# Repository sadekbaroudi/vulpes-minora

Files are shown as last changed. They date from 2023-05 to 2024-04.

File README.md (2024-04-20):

# vulpes minora

This is a 36 key split pcb, specifically designed with the intent to demonstrate a VIK certified keyboard. Read all about that in the [vik github repository](https://github.com/sadekbaroudi/vik)

## Features

vulpes minora supports the following features:
* 36 keys
* Reversible PCB
* MX / Choc / KS-27 and KS-33 switch support, hotswap only
* Underglow
* EC11 rotary encoders (byo-mcu and RP2040-Zero version only)
* Audio buzzer (byo-mcu only)
* VIK support (byo-mcu and RP2040-Zero version only)
* Wireless + VIK support (using nice!nano controller, byo-mcu version only)

Note: while the xiao-xivik version doesn't support VIK, the intent of this PCB is to allow you to build a vulpes majora using a [xivik controller](https://fingerpunch.xyz/product/xivik), which **does** provide you VIK support

## VIK keyboard certification card

| Category | Classification | Response |
| ---  | --- | --- |
| FPC connector | Required | :heavy_check_mark: |
| Breakout pins | Recommended | :x: |
| Supplies: SPI | Strongly recommended | :heavy_check_mark: |
| Supplies: I2C | Strongly recommended | :heavy_check_mark: |
| I2C on main PCB | Discouraged | :x: |
| I2C pull ups | Informative | N/A |
| Supplies: RGB | Strongly recommended | :heavy_check_mark: |
| Supplies: Extra GPIO | Strongly recommended | :heavy_check_mark: |

## Build pics

This is a build using the [byo-mcu pcb](https://github.com/sadekbaroudi/vulpes-minora/tree/master/pcb/byo-mcu) keyboard pcb and the [per56-cirque-leds](https://github.com/sadekbaroudi/vik/tree/master/pcb/per56-cirque-leds) module.

vulpes-minora-cirque-scroll-wheel-full-in-dark

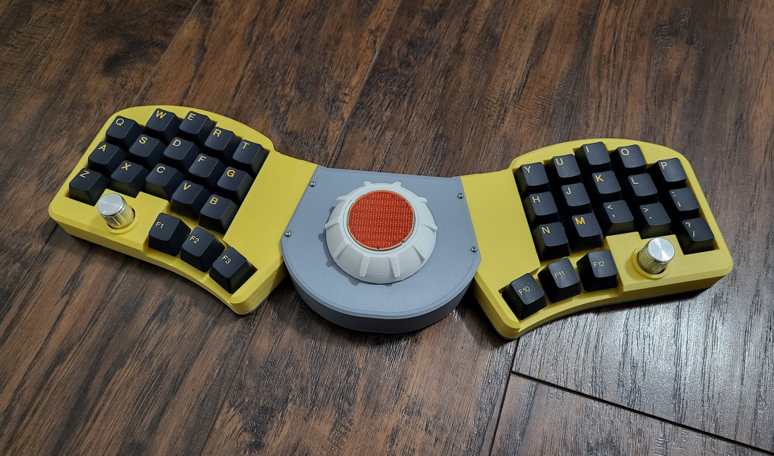
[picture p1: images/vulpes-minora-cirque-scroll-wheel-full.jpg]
vulpes-minora-cirque-scroll-wheel-full


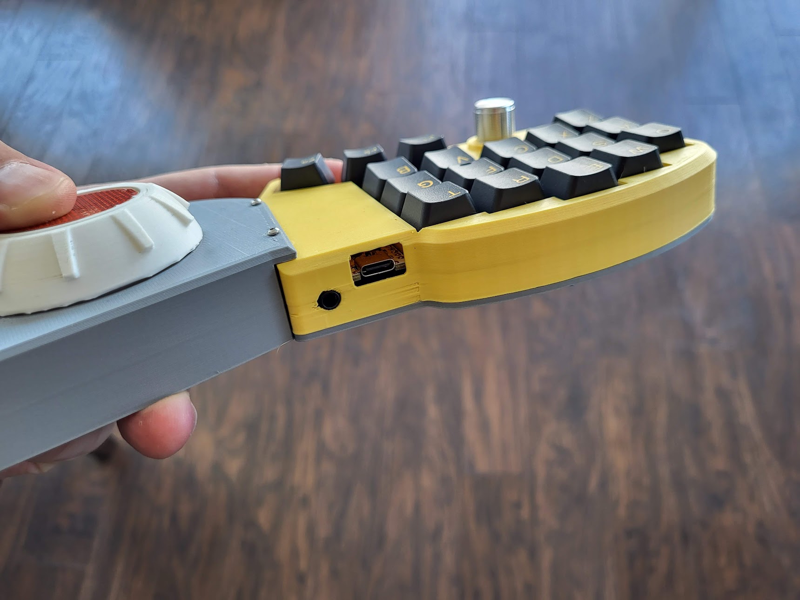
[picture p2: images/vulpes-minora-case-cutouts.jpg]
vulpes-minora-case-cutouts


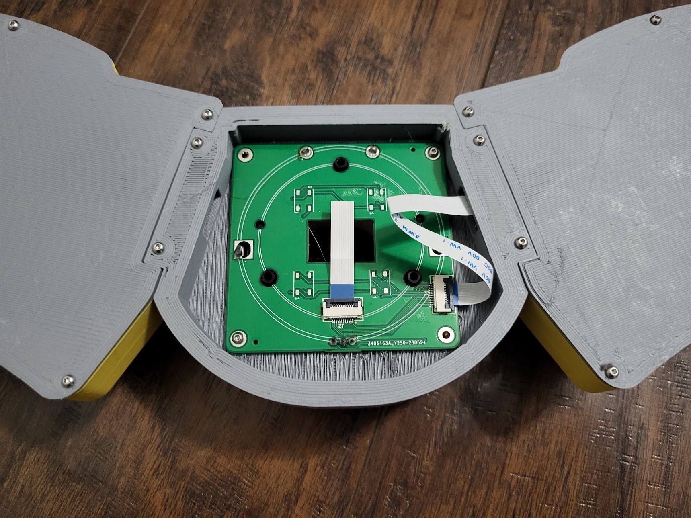
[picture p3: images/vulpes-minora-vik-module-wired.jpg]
vulpes-minora-vik-module-wired


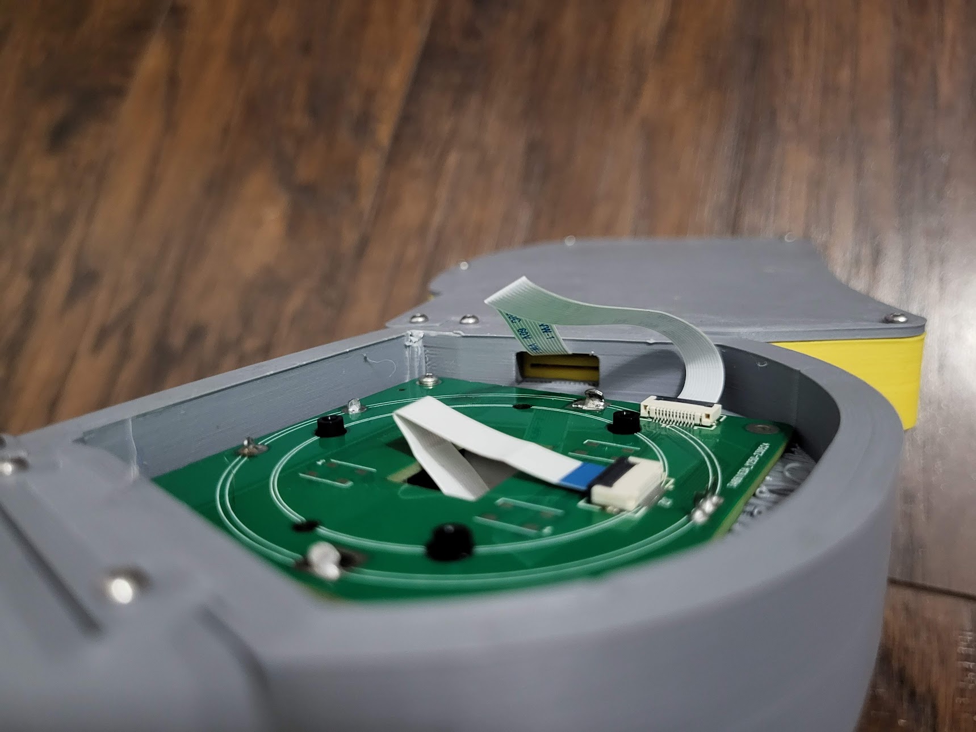
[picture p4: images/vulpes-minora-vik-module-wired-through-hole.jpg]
vulpes-minora-vik-module-wired-through-hole


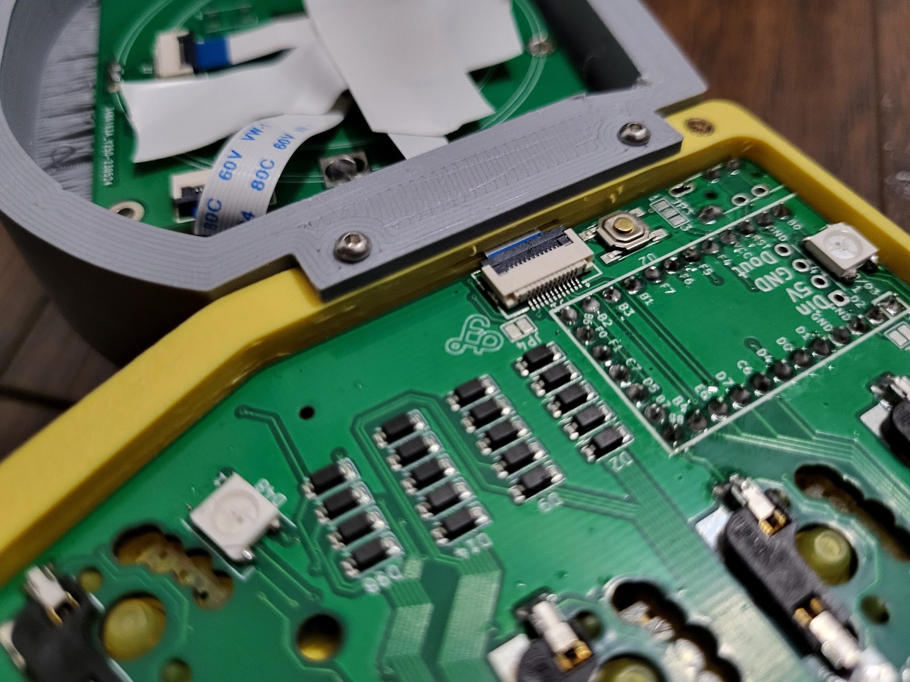
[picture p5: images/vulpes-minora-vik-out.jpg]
vulpes-minora-vik-out


## Fabrication

You can make this board yourself! I recommend [JLCPCB](https://jlcpcb.com/).

All you need to do is upload the gerber.zip found in the production folder of either the byo-mcu or rp2040-zero folders. I also recommend you do PCBA. If you'd like to do this, you can use the bom.csv and positions.csv in the same folder.

## Firmware

See QMK firmware here:

https://github.com/sadekbaroudi/qmk_firmware/tree/master/keyboards/fingerpunch/vulpes_minora

## Bill of materials

### PCB (byo-mcu)

| Part name | Part Link (example) | Required | Quantity |
| --- | --- | --- | --- |
| SOD-123 1N4148W diodes | https://www.lcsc.com/product-detail/Switching-Diode_GOODWORK-1N4148W_C909967.html | :heavy_check_mark: | 36 (38 if using EC11 ) |
| TRRS jack | https://www.amazon.com/uxcell-Audio-Connector-Mount-Socket/dp/B0BJJW9KVZ | :heavy_check_mark: | 2 |
| Hotswap sockets (MX, choc, or ks-27/33) | No link, easy to find these | :heavy_check_mark: | 36 |
| RP2040 elite-c footprint compatible controller (elite-pi, splinky) | https://keeb.io/products/elite-pi-usb-c-pro-micro-replacement-rp2040 <br /> https://github.com/plut0nium/0xB2 <br /> https://github.com/0xCB-dev/0xCB-Helios | :heavy_check_mark: | 2 |
| nice!nano for wireless build (replaces RP2040 controller) | No link, easy to find these | :heavy_check_mark: | 2 |
| (wireless only) OS102011MA1QN1 - on/off switch | Search for part number | :heavy_check_mark: | 2 |
| (wireless only) JST 2 pin connector, S2B-PH-K-S | https://www.digikey.com/en/products/detail/jst-sales-america-inc./S2B-PH-K-S/926626 | :heavy_check_mark: | 2 |
| (wireless only) DC-DC step up (VIK 3.3v to 5v, not req for most VIK modules) | Open kicad schematic, review parts that say "Batt -> 5V step up for VIK". Looks at LCSC value and search lcsc.com for part | :x: | 2 for each pert |
| SKQGA* (example SKQGADE010) - reset switch | https://www.lcsc.com/product-detail/Tactile-Switches_ALPSALPINE-SKQGADE010_C116647.html | :heavy_check_mark: | 2 |
| WS2812B leds (recommended for wired only) | https://www.lcsc.com/product-detail/Light-Emitting-Diodes-LED_Worldsemi-WS2812B-B-T_C2761795.html | :x: | 12 |
| VIK connector (FPC 12 pin 0.5mm pitch) | https://www.lcsc.com/product-detail/FFC-FPC-Connectors_SHENZHEN-ATOM-TECH-FPC05012-09200_C479750.html | :x: | 2 |
| EC-11 encoders | No link, easy to find these | :x: | 2 |
| Audio buzzer (KLJ-1102) | https://www.lcsc.com/product-detail/Buzzers_KELIKING-KLJ-1102_C201047.html | :x: | 2 |

### Module

For the module, see the [VIK repository](https://github.com/sadekbaroudi/vik) for a list of [VIK compatible modules](https://github.com/sadekbaroudi/vik#known-list-of-vik-certifications).

## Build instructions

### byo-mcu (wired vs wireless)

When building the byo-mcu PCB, you can use a RP2040 elite-c footprint compatible controller, or you can use a nice!nano for wireless.

vulpes-minora-byo-mcu-side2.png

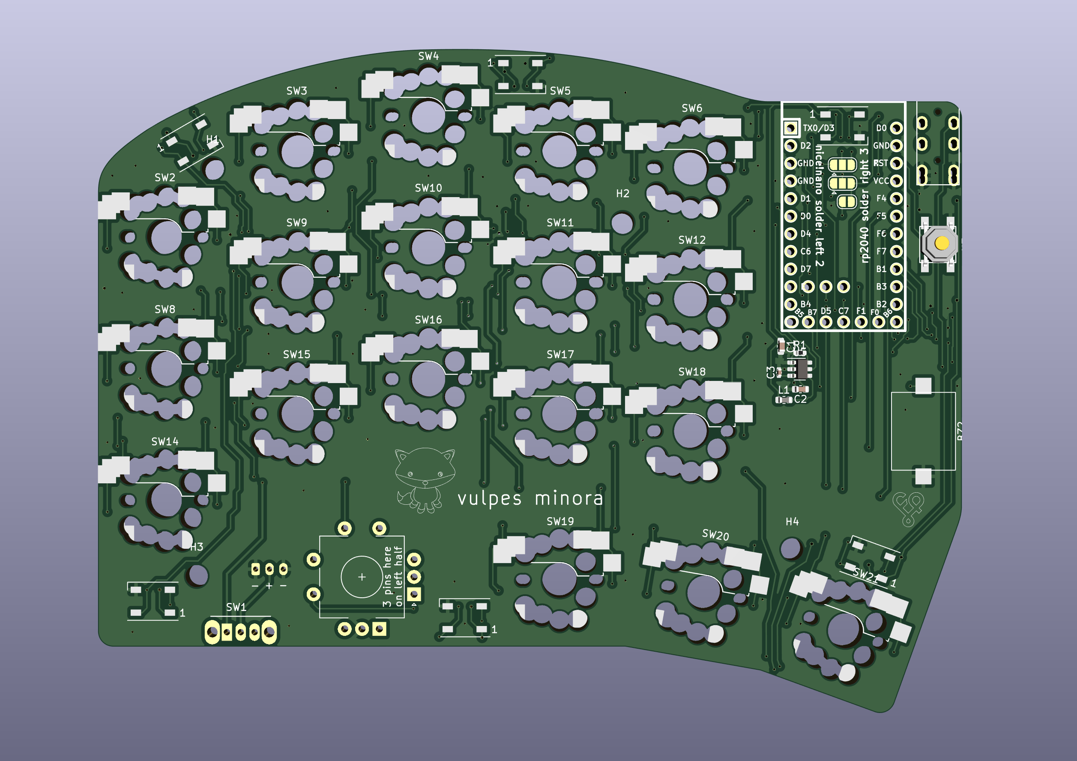
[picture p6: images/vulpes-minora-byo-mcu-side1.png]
vulpes-minora-byo-mcu-side1


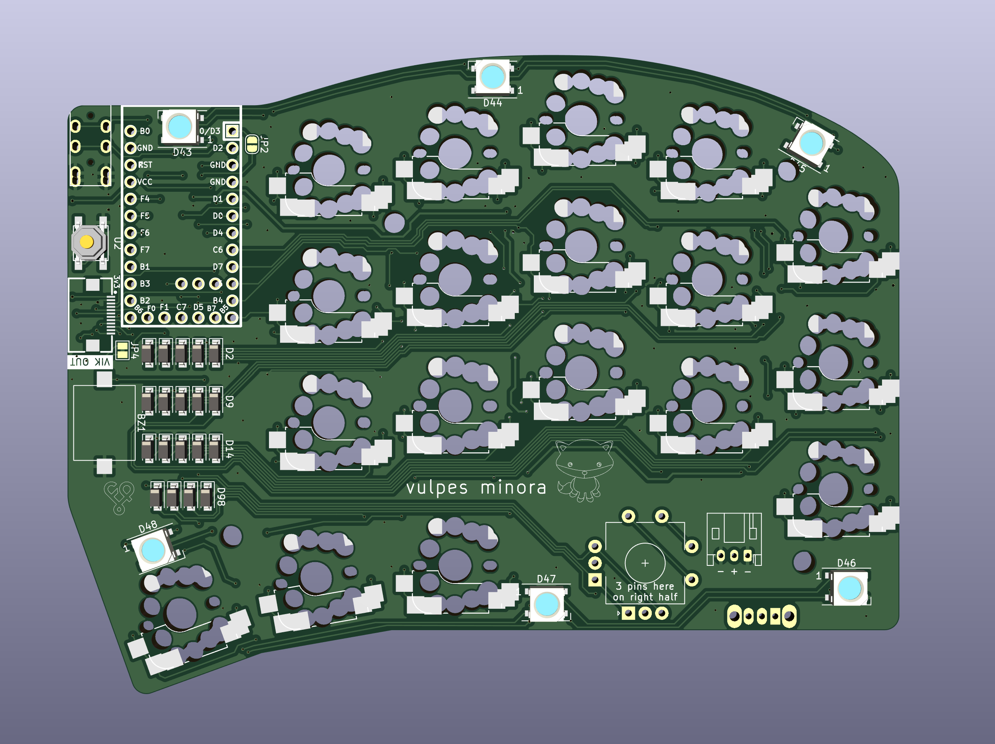
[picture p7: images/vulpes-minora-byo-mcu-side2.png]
vulpes-minora-byo-mcu-side2


Depending on which controller you use, you will need to solder certain pads. Certain components will be required for one build, and should not be included in the other. See the images below as a reference for this:

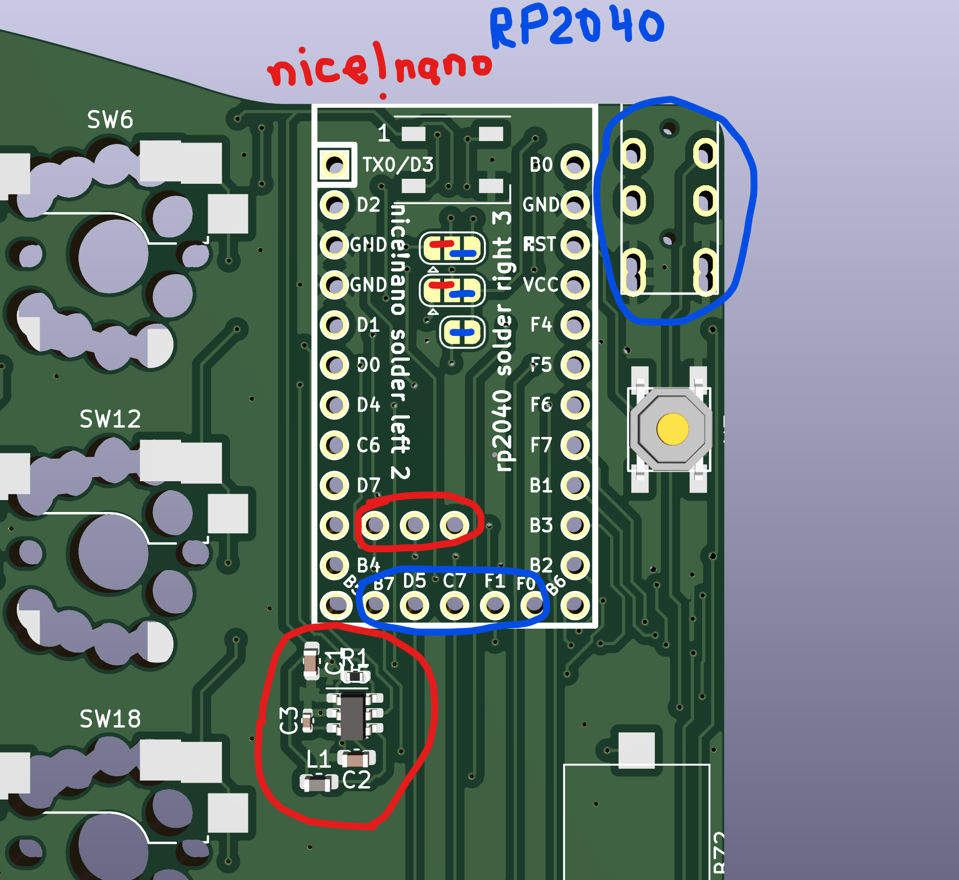
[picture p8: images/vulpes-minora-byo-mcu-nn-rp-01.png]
vulpes-minora-byo-mcu-nn-rp-01


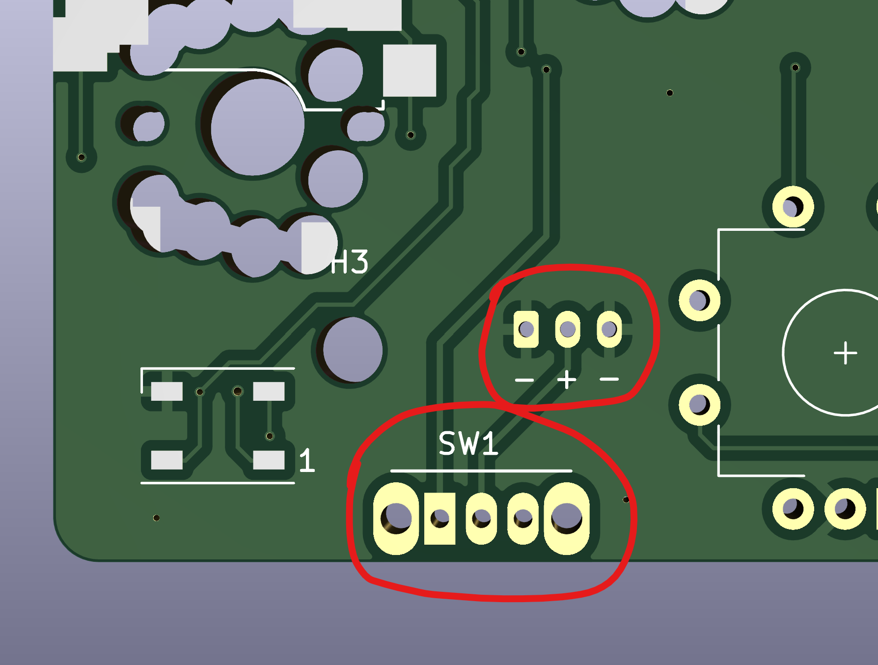
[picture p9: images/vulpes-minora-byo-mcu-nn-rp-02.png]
vulpes-minora-byo-mcu-nn-rp-02


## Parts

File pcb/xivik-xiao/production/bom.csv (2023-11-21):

Designator | Footprint | Quantity | Value | LCSC Part #
D10, D11, D12, D14, D15, D16, D17, D18, D19, D2, D20, D21, D3, D4, D5, D6, D8, D9 | D_SOD-123 | 18 | 1N4148W | C909967
D43, D44, D45, D46, D47, D48 | LED_WS2812B_PLCC4_5.0x5.0mm_P3.2mm-reversible | 6 | WS2812B | C2761795
H1, H2, H3, H4 | MountingHole_3.2mm_M3 | 4 | MountingHole
J13 | Connector_THT_1x4_2.54 | 1 | Conn_01x04_Female
J2, J3 | TRRS-PJ-320A | 2 | AudioJack4dpb
JP1 | SolderJumper-2_P1.3mm_Bridged_Pad1.0x1.5mm | 1 | SolderJumper_2_Bridged
JP2 | SolderJumper-2_P1.3mm_Open_Pad1.0x1.5mm | 1 | Jumper_2_Open
JP3 | SolderJumper-3_P1.3mm_Bridged12_Pad1.0x1.5mm_NumberLabels | 1 | SolderJumper_3_Bridged12
M1 | XIAO-RP2040_THT_ONLY | 1 | XIAO-BLE
SW10, SW11, SW12, SW14, SW15, SW16, SW17, SW18, SW19, SW2, SW20, SW21, SW3, SW4, SW5, SW6, SW8, SW9 | gateron-ks27-choc-v1-mx-hotswap-reversible | 18 | SW_Push
U2, U3 | SKQG-1155865 | 2 | SW_Push

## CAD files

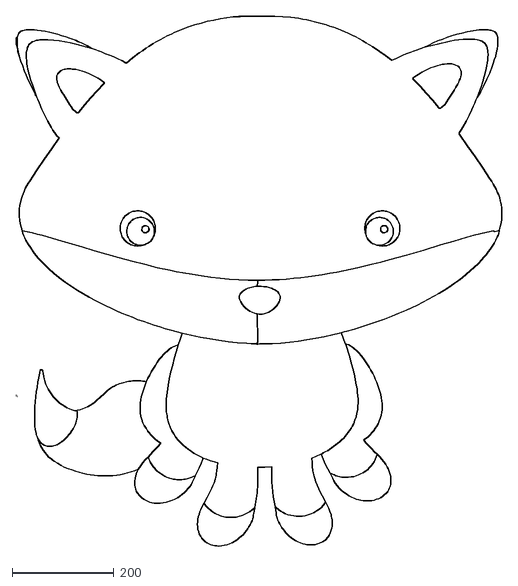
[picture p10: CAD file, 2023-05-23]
baby-fox-bw.dxf
957.5 x 1044.2

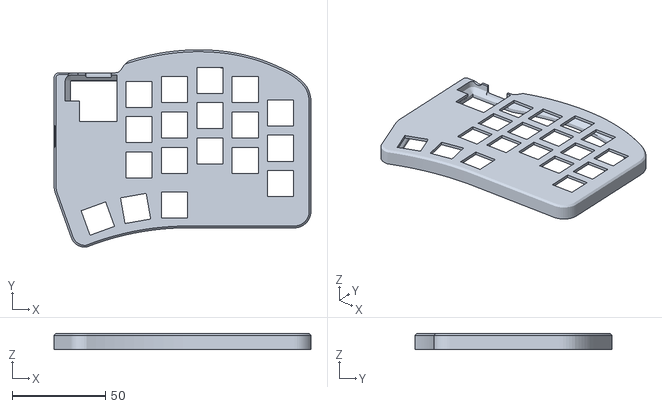
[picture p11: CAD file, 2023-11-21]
case/choc/vmin-rp2040zero-choc-ne-TPU-right.stl
138.1 x 106.0 x 8.60

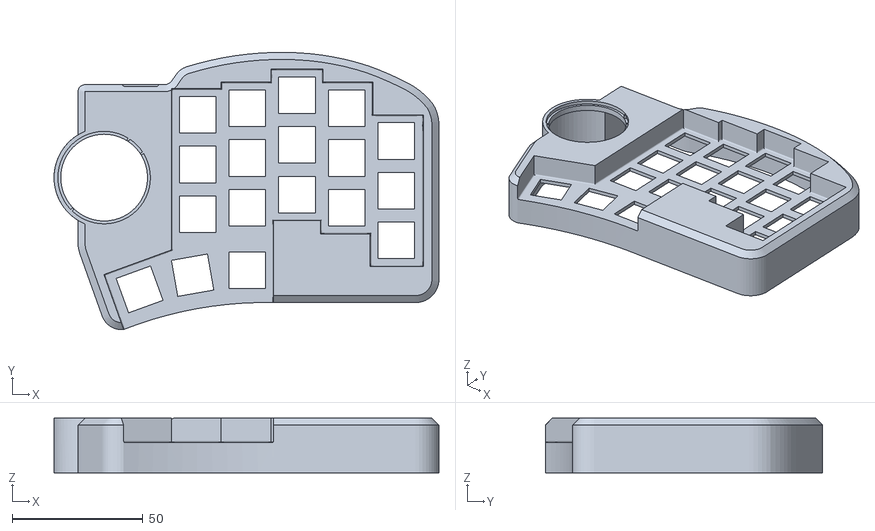
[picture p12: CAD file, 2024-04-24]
case/mx/vmin-mx-cirque-body-right.stl
147.3 x 106.0 x 21.0

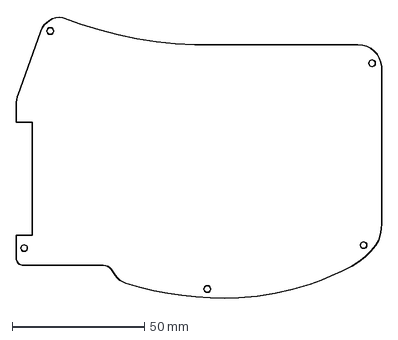
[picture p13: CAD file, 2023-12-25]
case/vulpes-minora-bottom.dxf
138.2 x 107.0 mm

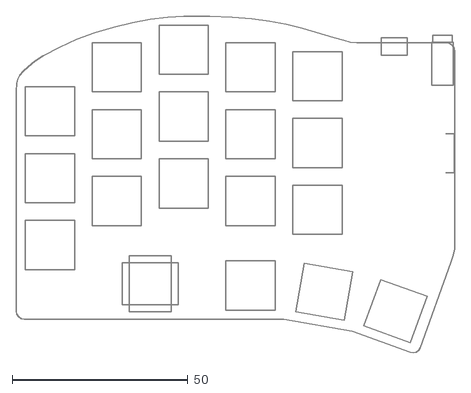
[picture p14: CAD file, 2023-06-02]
pcb/xivik-xiao/svgs/vulpes-minora-brd.dxf
124.6 x 95.6

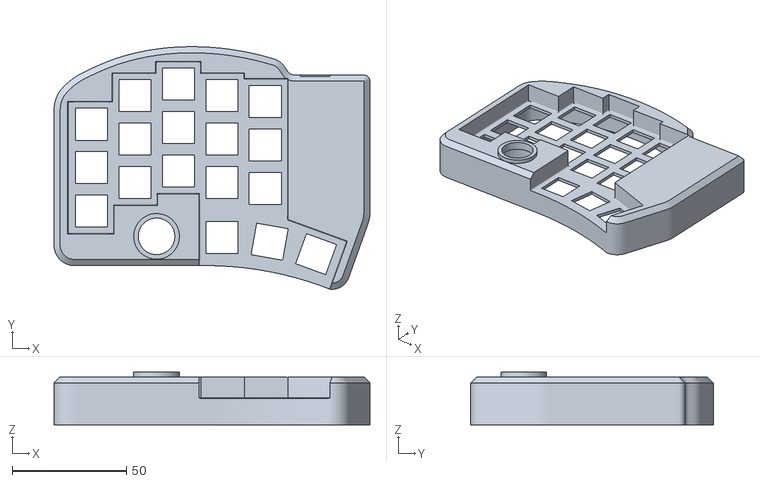
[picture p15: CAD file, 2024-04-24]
case/mx/vmin-mx-no-vik-ec11-body-left.stl
138.1 x 106.0 x 23.0

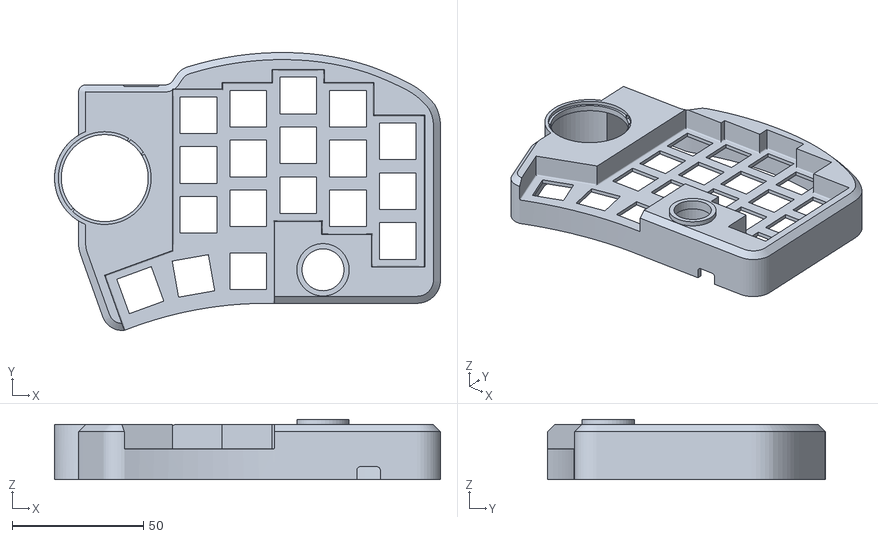
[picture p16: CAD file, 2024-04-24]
case/mx/vmin-mx-wireless-cirque-ec11-body-right.stl
147.3 x 106.0 x 23.0

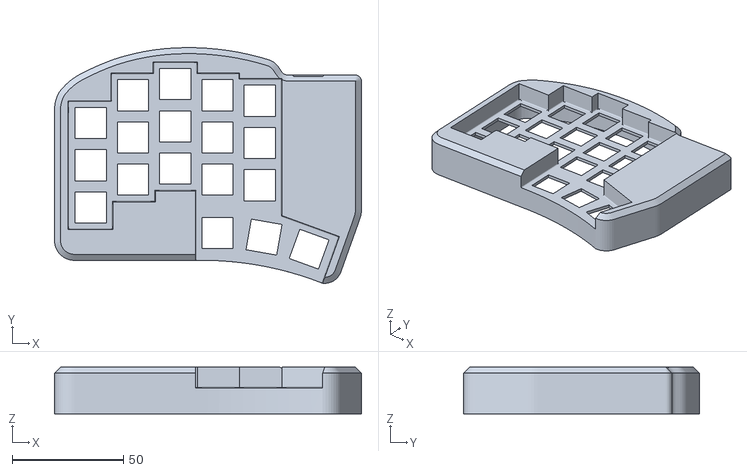
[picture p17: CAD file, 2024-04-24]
case/mx/vmin-mx-no-vik-body-left.stl
138.1 x 106.0 x 21.0

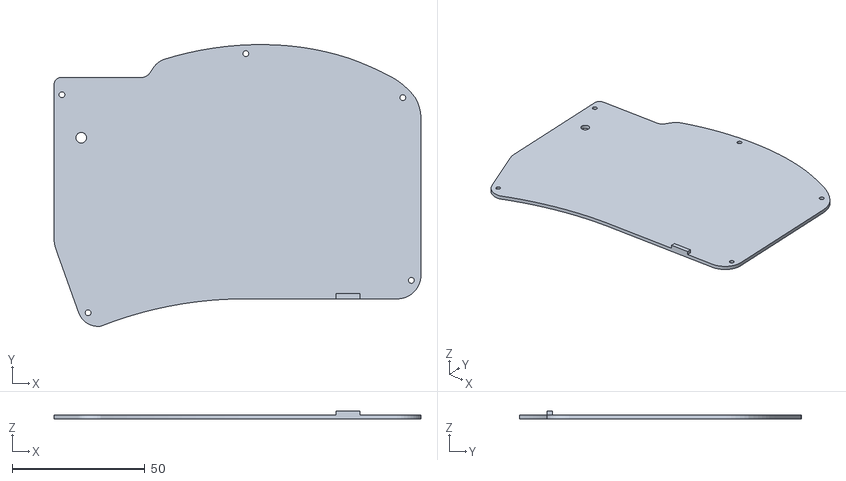
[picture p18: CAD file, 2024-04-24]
case/mx/vmin-mx-wireless-no-vik-bottom-right.stl
138.1 x 106.0 x 3.10

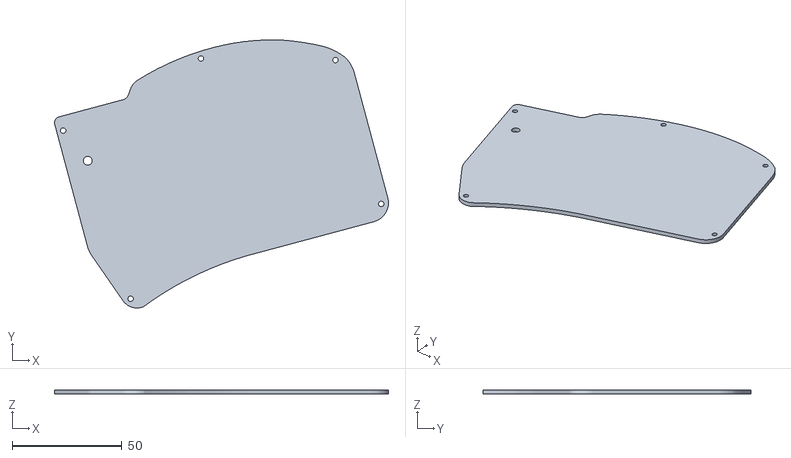
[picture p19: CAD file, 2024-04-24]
case/mx/vmin-mx-no-vik-bottom-right.stl
152.4 x 122.3 x 2.00

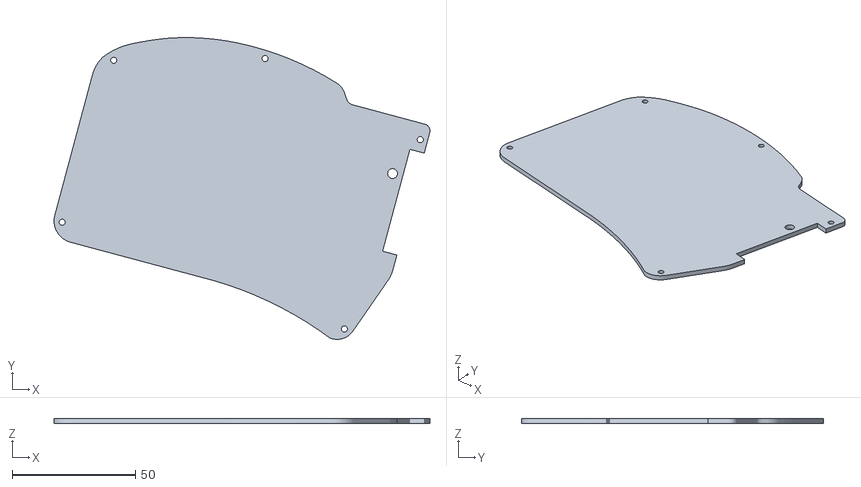
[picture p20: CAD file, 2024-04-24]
case/mx/vmin-mx-bottom-left.stl
152.4 x 122.3 x 2.00

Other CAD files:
case/choc/vmin-rp2040zero-choc-ne-TPU-left.stl
case/mx/vmin-mx-wireless-cirque-body-left.stl
case/mx/vmin-mx-wireless-cirque-ec11-body-left.stl
case/mx/vmin-mx-wireless-no-vik-body-left.stl
case/mx/vmin-mx-wireless-no-vik-body-right.stl
case/mx/vmin-mx-no-vik-ec11-body-right.stl
case/mx/vmin-mx-cirque-body-left.stl
case/mx/vmin-mx-bottom-right.stl
case/mx/vmin-mx-cirque-bottom-left.stl
case/mx/vmin-mx-cirque-bottom-right.stl
case/mx/vmin-mx-cirque-ec11-body-left.stl
case/mx/vmin-mx-cirque-ec11-body-right.stl
case/mx/vmin-mx-ec11-body-left.stl
case/mx/vmin-mx-ec11-body-right.stl
case/mx/vmin-mx-no-vik-body-right.stl
case/mx/vmin-mx-no-vik-bottom-left.stl
case/mx/vmin-mx-vik-peacock.stl
case/mx/vmin-mx-wireless-cirque-body-right.stl
case/mx/vmin-mx-wireless-cirque-bottom-left.stl
case/mx/vmin-mx-wireless-cirque-bottom-right.stl
case/mx/vmin-mx-wireless-no-vik-bottom-left.stl
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

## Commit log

2023-05-23 first commit of vulpes minora, with gerbers... need to triple check everything though
    [bom.csv, designators.csv, positions.csv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]
2023-05-23 fixed the jumper that allows you to select between 5v, or RAW, and 3v, or VCC
    [vulpes-minora.kicad_pcb, vulpes-minora.kicad_sch]
2023-05-23 added baby fox logo
    [baby-fox-bw.dxf, designators.csv, vulpes-minora.kicad_pcb]
2023-05-23 added comments for encoder placement, fixed ws2812b in bom
    [bom.csv, vulpes-minora.kicad_pcb, vulpes-minora.kicad_sch]
2023-05-23 updated voltron to be natively compatible with cirque regarding data ready pin, also added jumper to remove 5v to make the cirque directly pluggable into the connector
    [bom.csv, designators.csv, vulpes-minora.kicad_pcb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]
2023-06-01 updated to make exporting svg easier for sketch for 3d modeling case
    [vulpes-minora.kicad_pcb, vulpes-minora.kicad_sch]
2023-06-02 minor sync, no functional changes
    [vulpes-minora-brd.dxf, vulpes-minora.kicad_sch]
2023-06-03 added a case and VIK pers60 and cirque attachment, still haven't been tested
    [vmin-mx-bottom-left.stl, vmin-mx-bottom-right.stl, vmin-mx-ec11-body-left.stl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]
2023-06-03 fixed 3 switch type hotswap reversible footprint, and moved audio buzzer to the side of the pcb so that low profile builds don't interfere regardless of which side the buzzer is on
    [positions.csv, vulpes-minora.kicad_pcb]
2023-06-04 made some small adjustments, accommodating top mounted LEDs, and ensuring that the scroll wheel mount was properly connected
    [vmin-pers-cirque-mount-scrollwheel.stl, vmin-pers-cirque-mount.stl]
2023-06-04 fixed the cirque mount to be more sturdy, and added a slightly taller one in case the scroll wheel is a bit too tall, which depends on how it was soldered
    [vmin-pers-cirque-mount-1mm-taller.stl, vmin-pers-cirque-mount.stl]
2023-06-05 cleaned up excess footprints and symbols, and implemented using the VIK symbols and footprints
    [bom.csv, designators.csv, positions.csv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]
2023-06-06 added in and out labels to connector footprint, and republished gerbers
    [bom.csv, vulpes-minora.kicad_pcb, vulpes-minora.kicad_sch]
2023-06-09 added RP2040-Zero edition of vulpes minora
    [bom.csv, designators.csv, positions.csv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]
2023-06-12 updated all footprints to include the 3v3 label so it's easier to verify correct cable insertion when using the pcbs
    [vulpes-minora.kicad_pcb]
2023-06-17 fixed reversible 3 switch type footprints and regenerated gerbers
    [vulpes-minora.kicad_pcb]
2023-06-26 updated vulpes minora to match new vik standard of two gpio, corresponding to commit 57a4fb79db6f66c8cfaf2971141367c47d66a44f in the vik repo
    [bom.csv, designators.csv, positions.csv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]
2023-07-07 spacing on vik through hole footprint was 2mm, but should have been 2.54
2023-07-07 forgot vertical spacing on the last commit - spacing on vik through hole footprint was 2mm, but should have been 2.54
2023-07-29 updated readme to include pictures, fab instructions, and bom
2023-07-30 added feature list, and audio buzzer to bom
2023-09-01 added TPU printable rp2040 zero case
    [vmin-rp2040zero-choc-ne-TPU-left.stl]
2023-11-21 TPU slip on case for vulpes minora
    [vmin-rp2040zero-choc-ne-TPU-left.stl, vmin-rp2040zero-choc-ne-TPU-right.stl]
2023-11-21 new xivik-xiao version of the vulpes minora
    [bom.csv, designators.csv, positions.csv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]
2023-12-01 added xivik cases with mounting hole cutout for trackpoint
    [vmin-xivik-mx-body-left.stl, vmin-xivik-mx-body-right.stl]
2023-12-03 waveshare 22224 display case module add on for xivik mx case
    [vmin-xivik-mx-vik-waveshare-left.stl]
2023-12-25 added dxf for vulpes minora so you can cut a frosted acrylic bottom plate to show off the underglow
    [vulpes-minora-bottom.dxf]
2024-02-19 untested peacock trackpad vik module connector for vulpes minora case
    [vmin-mx-vik-peacock.stl]
2024-02-21 vik peacock cover stl
    [vmin-vik-peacock-cover.stl]
2024-04-20 added better wireless support for byomcu
    [bom.csv, designators.csv, positions.csv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]
2024-04-24 mx cirque cases for vulpes minora
    [vmin-mx-cirque-bottom-left.stl, vmin-mx-cirque-bottom-right.stl, vmin-mx-cirque-ec11-body-left.stl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]
2024-04-24 added a whole bunch of mx vulpes minora cases and plates
    [vmin-mx-bottom-left.stl, vmin-mx-bottom-right.stl, vmin-mx-cirque-body-left.stl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]
